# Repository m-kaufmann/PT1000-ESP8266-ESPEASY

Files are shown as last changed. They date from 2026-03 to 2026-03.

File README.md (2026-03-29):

# PT1000 Temperaturmessung mit ESP8266 und MAX31865

Dieses Projekt beschreibt eine einfache und kostengünstige Lösung zur Messung von **vier Temperaturen mit PT1000-Sensoren**.

Die Sensoren werden über **MAX31865 RTD-Interface-Module** ausgelesen und von einem **ESP8266 (Wemos D1 mini)** verarbeitet.  
Die Messwerte werden anschließend in **Home Assistant** integriert und können optional per **MQTT** weitergegeben werden.

Besonderheit dieses Projekts ist ein **kompaktes 3D-druckbares Gehäuse**, das speziell für diese Kombination entworfen wurde und Platz für:

- 1 × ESP8266 D1 mini  
- 4 × MAX31865 Module  
- Anschlussleitungen für die Sensoren  

Das Gehäuse ist ebenfalls in diesem Repository als **STL-Datei** enthalten.

---

# Projektübersicht

Das System besteht aus:

- ESP8266 D1 mini
- 4 × MAX31865 RTD-Interface
- 4 × PT1000 Sensoren
- gemeinsamem SPI-Bus
- Integration in Home Assistant
- optionalem MQTT-Export

---

# ⚠️ Wichtiger Hinweis zur Verdrahtung

Jeder PT1000 muss **mit beiden Leitungen ausschließlich an "sein" MAX31865-Modul angeschlossen werden**.

👉 Eine gemeinsame Rückleitung für mehrere Sensoren ist **nicht zulässig**.

Grund:
- führt zu Fehlmessungen
- erzeugt sporadische Faults
- kann komplette Messketten stören

👉 Jeder Sensor benötigt eine **separate Zweidrahtleitung direkt zum jeweiligen MAX-Modul**

---

# Hardware

Verwendete Komponenten:

- ESP8266 **Wemos D1 mini**
- 4 × **MAX31865 RTD Interface**
- 4 × **PT1000 Temperaturfühler**

---

## Referenzwiderstand

Viele MAX31865-Boards sind standardmäßig für **PT100** ausgelegt  
(**Rref = 430 Ω**).

Für PT1000 muss der Referenzwiderstand auf etwa **4.3 kΩ** geändert werden.

Hier wurde der Widerstand ersetzt durch:
4.7 kΩ || 47 kΩ ≈ 4.27 kΩ

Der originale SMD-Widerstand wurde entfernt und durch zwei parallel geschaltete Drahtwiderstände ersetzt.

Wichtig:  
Nach dem Austausch sollten die Referenzwiderstände **gemessen** werden.  
Diese Werte werden anschließend **in ESPHome eingetragen**.

### Gemessene Referenzwerte

| Sensor | Rref |
|---|---|
| Sensor 1 | 4247 Ω |
| Sensor 2 | 4265 Ω |
| Sensor 3 | 4267 Ω |
| Sensor 4 | 4260 Ω |

---

# Verdrahtung

Alle MAX31865-Module teilen sich den gleichen **SPI-Bus**.  
Jedes Modul besitzt jedoch eine eigene **Chip-Select Leitung**.

## SPI Bus

| ESP8266 Pin | Funktion |
|---|---|
| D5 (GPIO14) | SCK |
| D6 (GPIO12) | MISO |
| D7 (GPIO13) | MOSI |

---

## Chip Select

| Sensor | ESP8266 Pin |
|---|---|
| MAX31865 #1 | D1 (GPIO5) |
| MAX31865 #2 | D3 (GPIO0) |
| MAX31865 #3 | D2 (GPIO4) |
| MAX31865 #4 | D0 (GPIO16) |

---

## Versorgung

| Signal | Verbindung |
|---|---|
| 5.0V | MAX31865 VCC |
| GND  | MAX31865 GND |

---

# Firmware (ESPHome)

Die Firmware basiert auf **ESPHome**.

## Konfiguration

Jeder MAX31865 wird als eigener Sensor betrieben:

- Sensor: **PT1000**
- Anschluss: **2-Wire**
- individueller Referenzwiderstand
- gemeinsamer SPI-Bus
- eigener CS-Pin je Modul

---

## Signalaufbereitung (Version 1)

Die aktuelle Konfiguration umfasst:

- Messintervall: **5 Sekunden**
- Filterung ungültiger Werte:
  - Kollektoren: **-20 °C bis +200 °C**
  - Solarleitungen: **0 °C bis +100 °C**
- Mittelwertbildung über **3 Messungen**
- Rundung auf **1 Nachkommastelle**

---

# Beispiel YAML (gekürzt)

```yaml
update_interval: 5000ms

filters:
  - lambda: |-
      if (isnan(x)) return {};
      if (x <= -20.0 || x >= 200.0) return {};
      return x;
  - sliding_window_moving_average:
      window_size: 3
      send_every: 3
  - round: 1

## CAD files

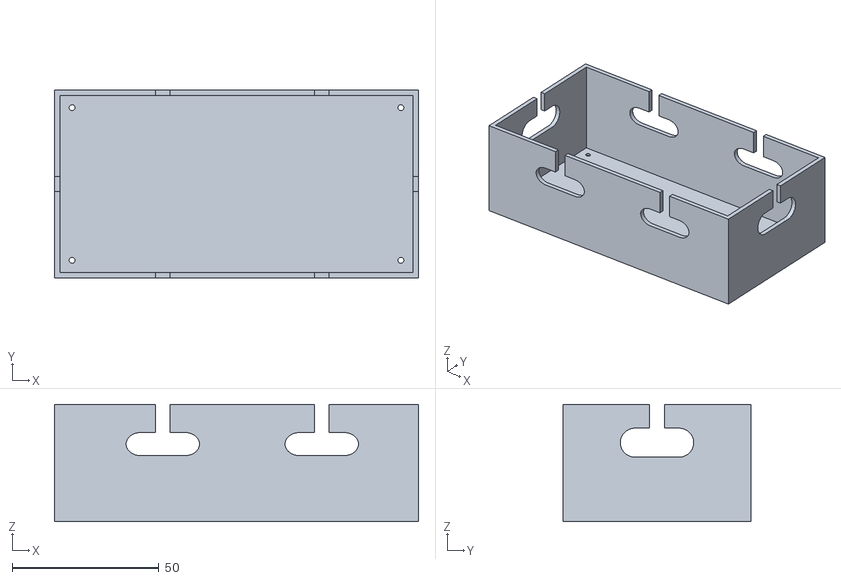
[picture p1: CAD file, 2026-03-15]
4xMAX31865_Gehäuse_2.stl
124.0 x 64.0 x 40.0

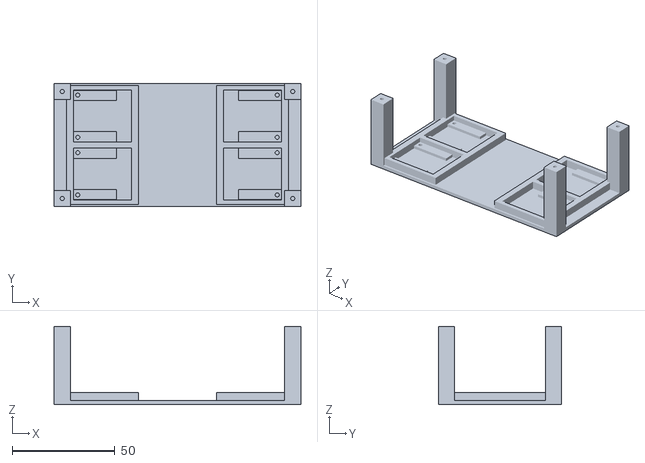
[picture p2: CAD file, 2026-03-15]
4xMAX31865_Gehäuse_1.stl
120.0 x 60.0 x 38.0

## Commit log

2026-03-15 Enhance README with resistor and firmware details
    Updated README with details on resistor replacement and voltage source.
2026-03-29 Enhance README with Home Assistant integration detailsVersion nach Umstellung von ESPEASY auf ESPHOME
    Updated the README to include integration with Home Assistant and clarified wiring instructions for PT1000 sensors. Changed references from ESPEasy to ESPHome and added example YAML configuration.
